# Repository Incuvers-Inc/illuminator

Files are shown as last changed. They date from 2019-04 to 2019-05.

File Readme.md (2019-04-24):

# Illuminator
LED Matrix illuminator for IRIS. Because, as any photographer will say, "good lighting is always needed to take a good picture."

## Hardware
- resistor network (one resistor per LED, 256 in total)
- 32x 74HC595 (for 256 outputs total)
- a dimming transistor for the fluorescence LED (5V PWM)
- a trigger transistor for the fluorescence LED (3.3V logic)
- a logic level shifter (four 3.3V -> 5V)
- capacitors to reduce kicks in current draw

### Power
The main power source will be used for the both illumination modules (matrix+ fluorescence LED). This can potentially blow the fuse is all of the components happen to be active at the same time. Luckily there is no requirement for them to simultaneously be active. The lighting flash is much shorter than the timescales for the environmental controls, so the latter can be disabled for the duration of the lighting flash. This must however be controlled by the software. Failure to account for this may result in a blown fuse.

### LED matrix
The fluorescence LED must first be disabled before the matrix LED is activated.

The LED matrix is driven by `74HC595` shift registers that can holds the state of up to 8 LEDs. The state of all the LED's must be first set before they are globally activated by grounding their shared `output_enable` pin.

#### Dimming
Global dimming is made possible with PWM on the `output_enable` input of the `74HC595`. All only one PWM signal is needed to dim the full matrix.

### Fluorescence LED
All the matrix LEDs must first be disabled before the fluorescence LED is lit.
The on/off state of the fluorescence LED is set from a single transistor.

#### Dimming
Dimming for the fluorescence LED is accomplished using the same PWM signal. In order for the matrix to stay off when the fluorescence LED is enabled, all the individual matrix LEDs must first be disabled.

### RPi interface
The RPi supplies inputs as the common PWM, fluorescence LED trigger, SPI for the matrix (three inputs) and of course a common ground.

Since the matrix is powered at 5V, the logic level (SPI and PWM) has to also be  shifted to 5V.

Since the fluorescence LED is trigger from a transistor, the logic level can stay at 3.3V.

## Software

### Illumination flash

The software must make sure that all the matrix LEDs are set to an `off` state after a pattern is finished flashing.
Iy may be good measure to be redundant and also do this before turning on the fluorescence LED.
The same goes for turning off the fluorescence LED before turning on the matrix.

### Power management

Since the LED's are powered from the main power source,
it is important to limit the total current draw from activated sub-components.
It is the software's responsibility to temporary disable components (heating/fans/valves) that could draw current for the duration of the illumination flash. Since this is rather short, it should cause any environmental noticeable disruptions.

NOTE: the activated camera sensor (and post processing) will also cause a short-lived increase in power demand, consider reactivating the environmental subcomponents only after the image is processed.

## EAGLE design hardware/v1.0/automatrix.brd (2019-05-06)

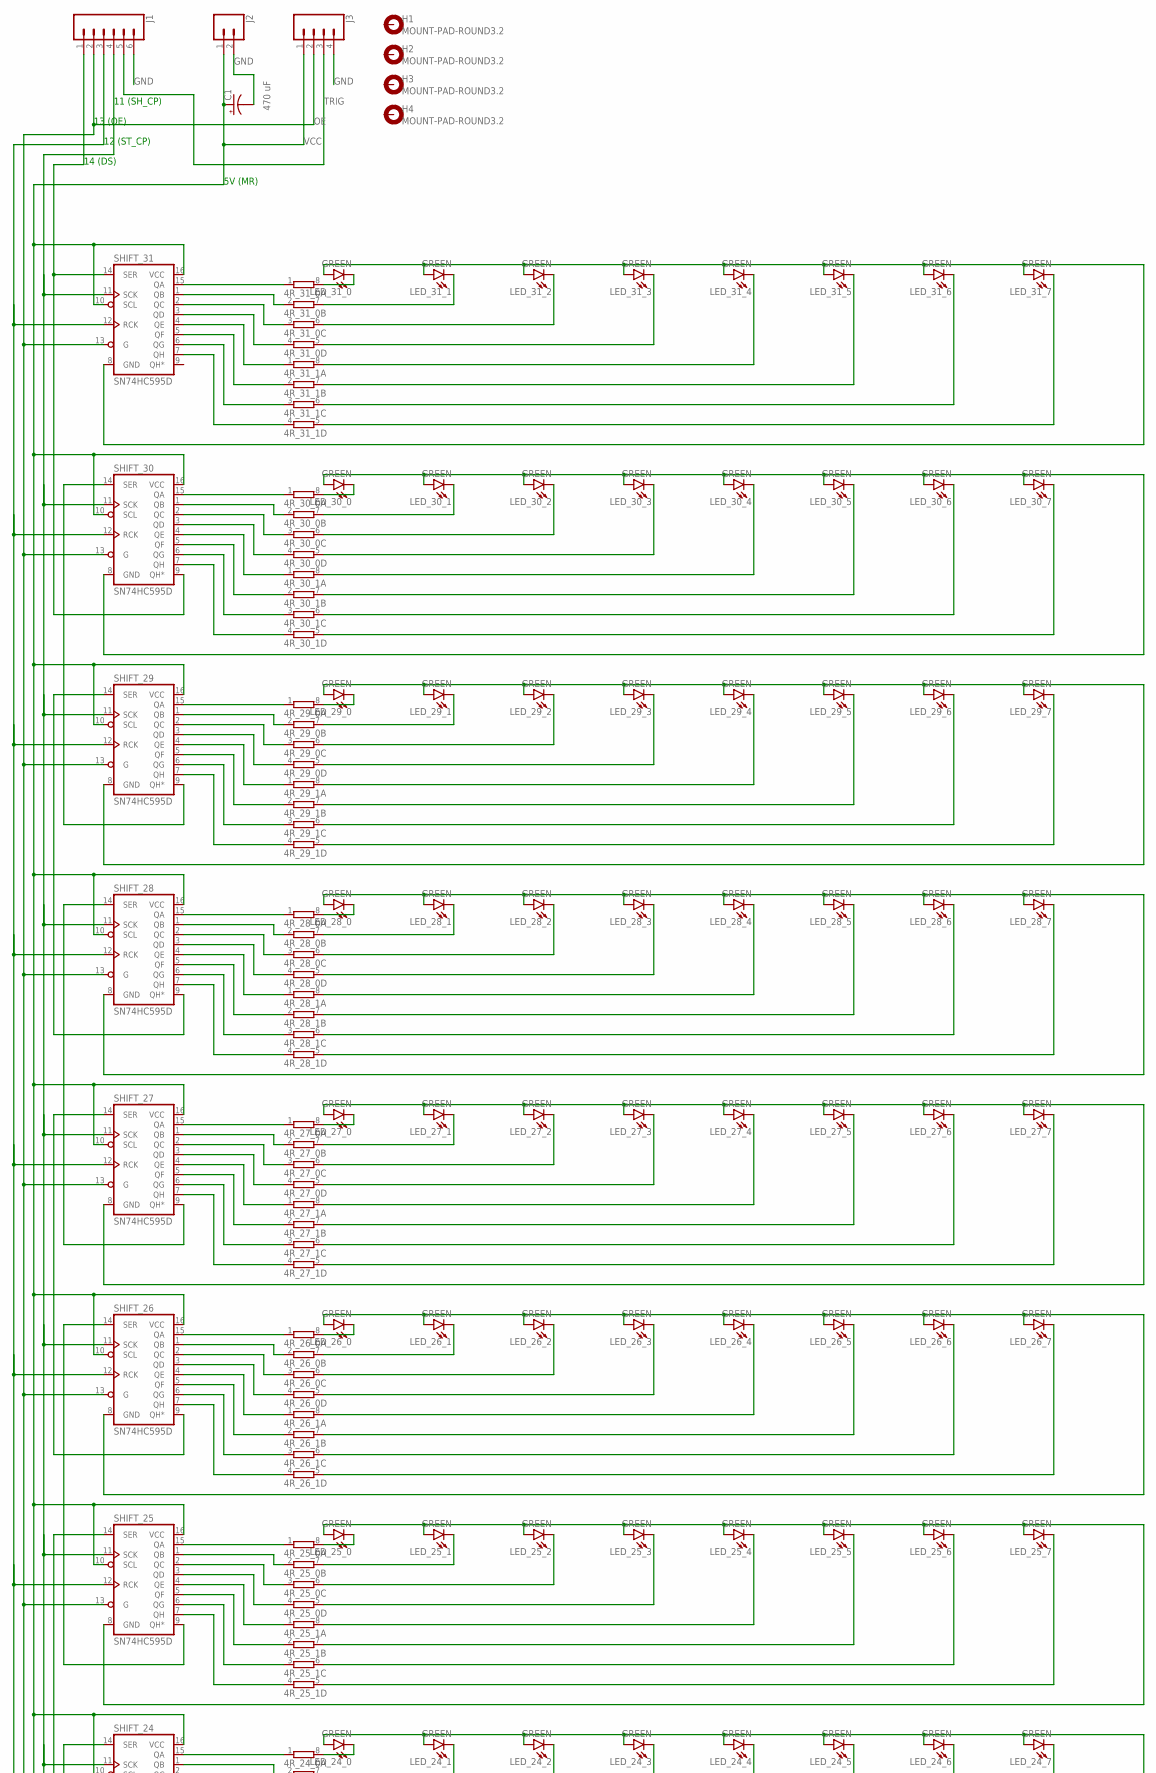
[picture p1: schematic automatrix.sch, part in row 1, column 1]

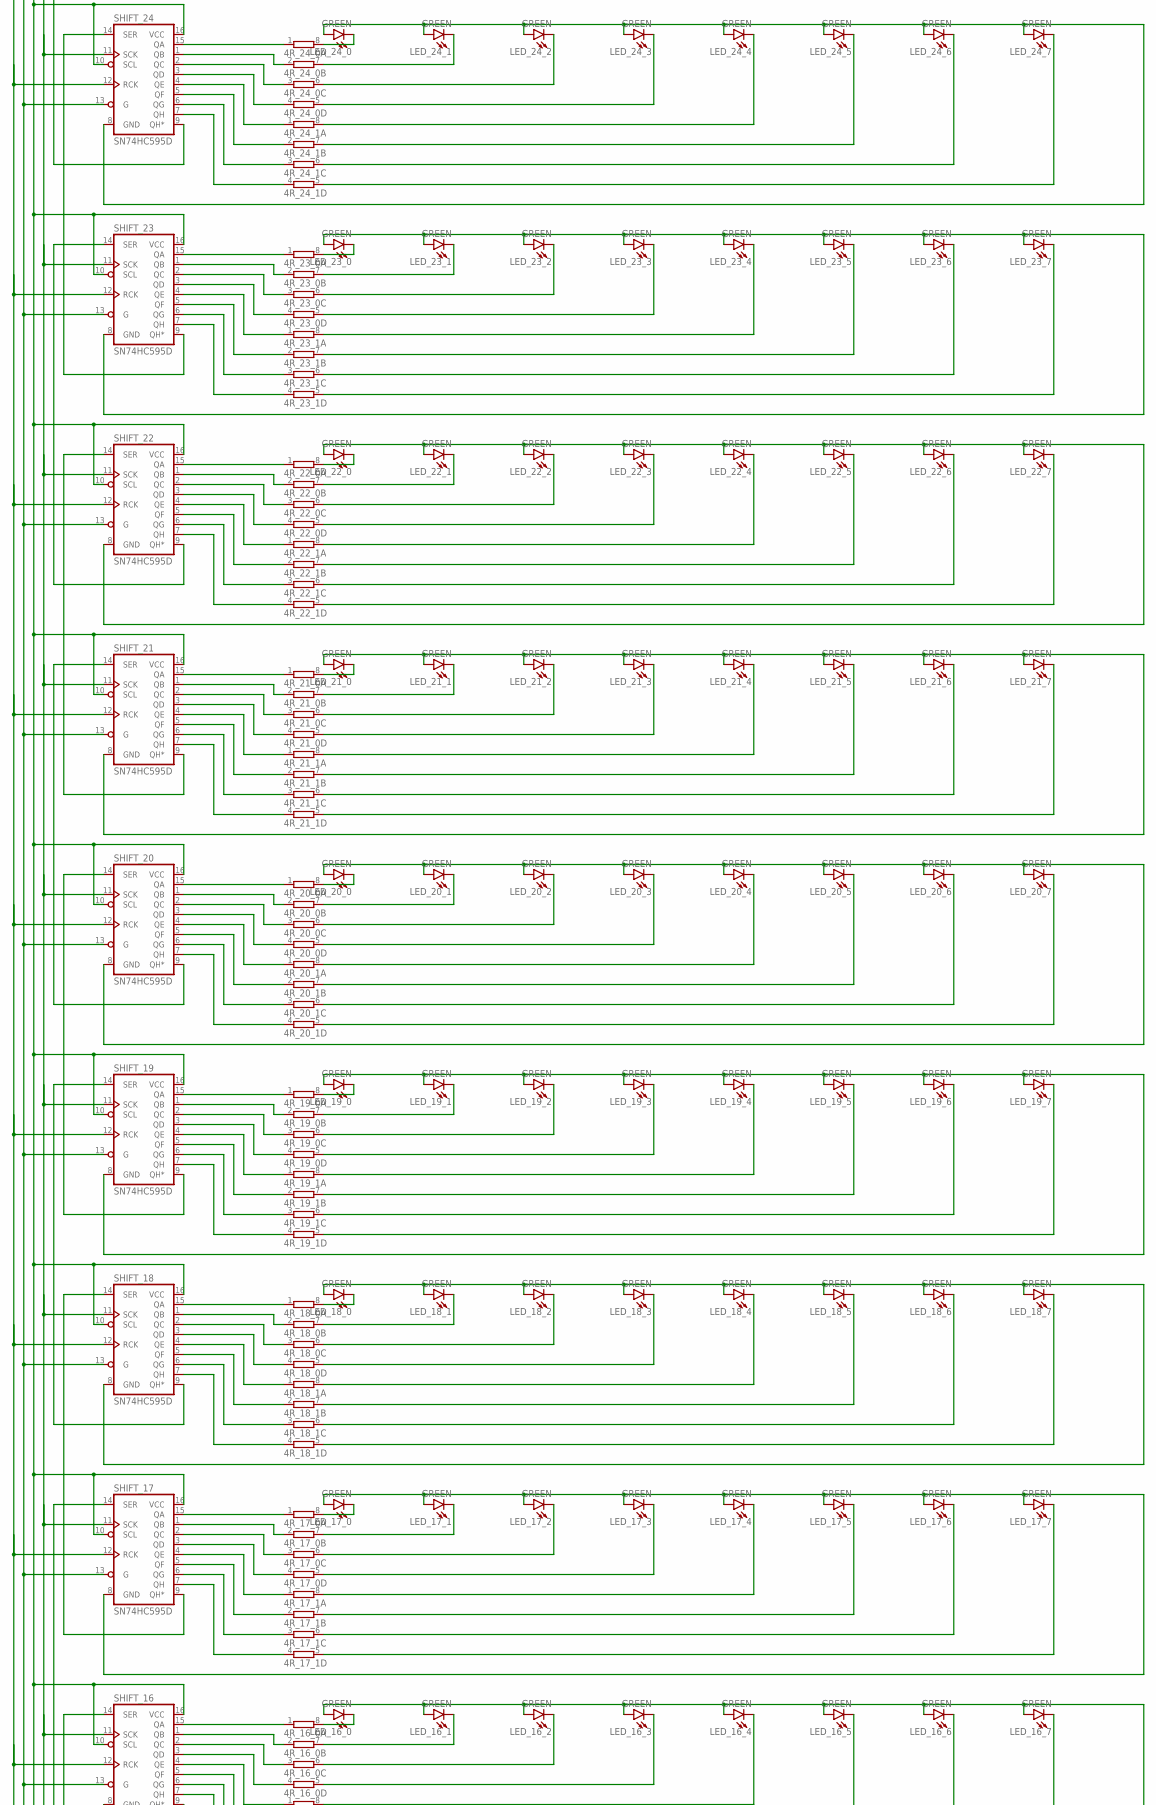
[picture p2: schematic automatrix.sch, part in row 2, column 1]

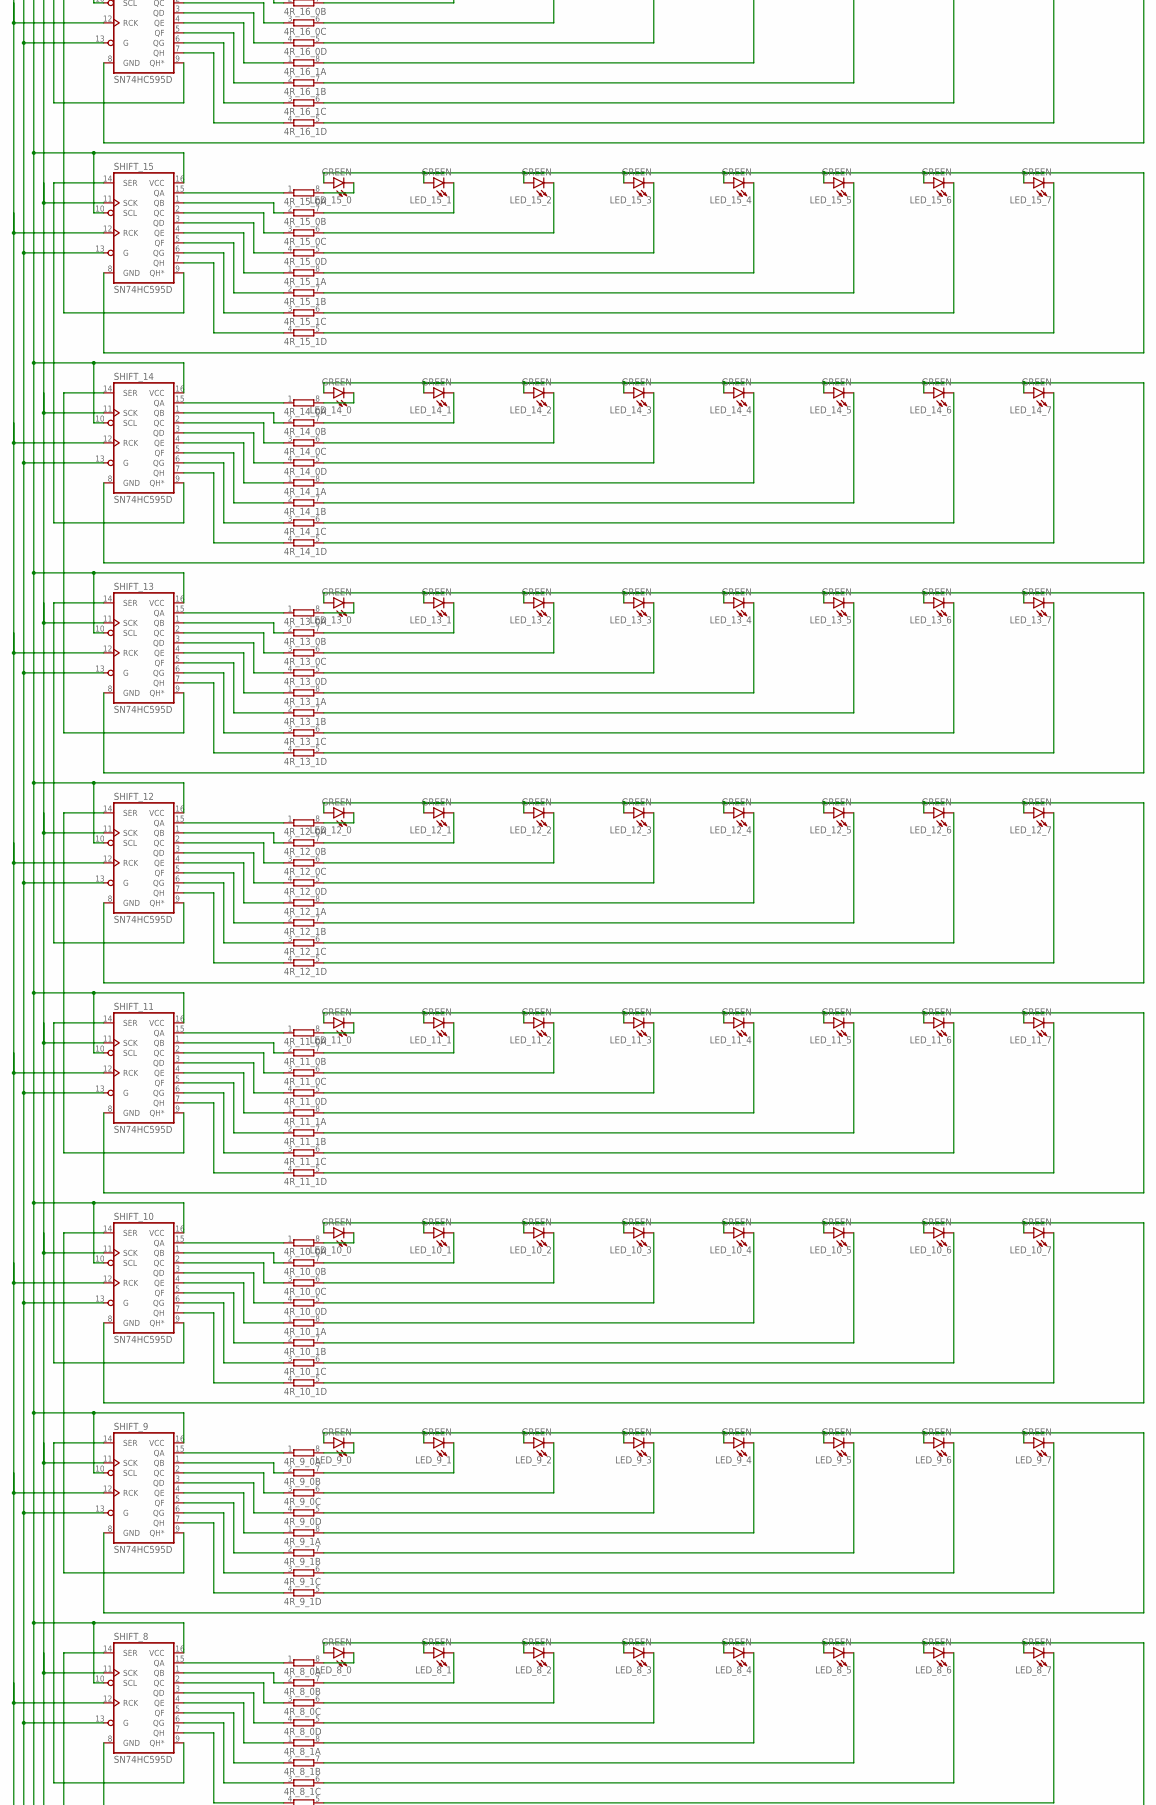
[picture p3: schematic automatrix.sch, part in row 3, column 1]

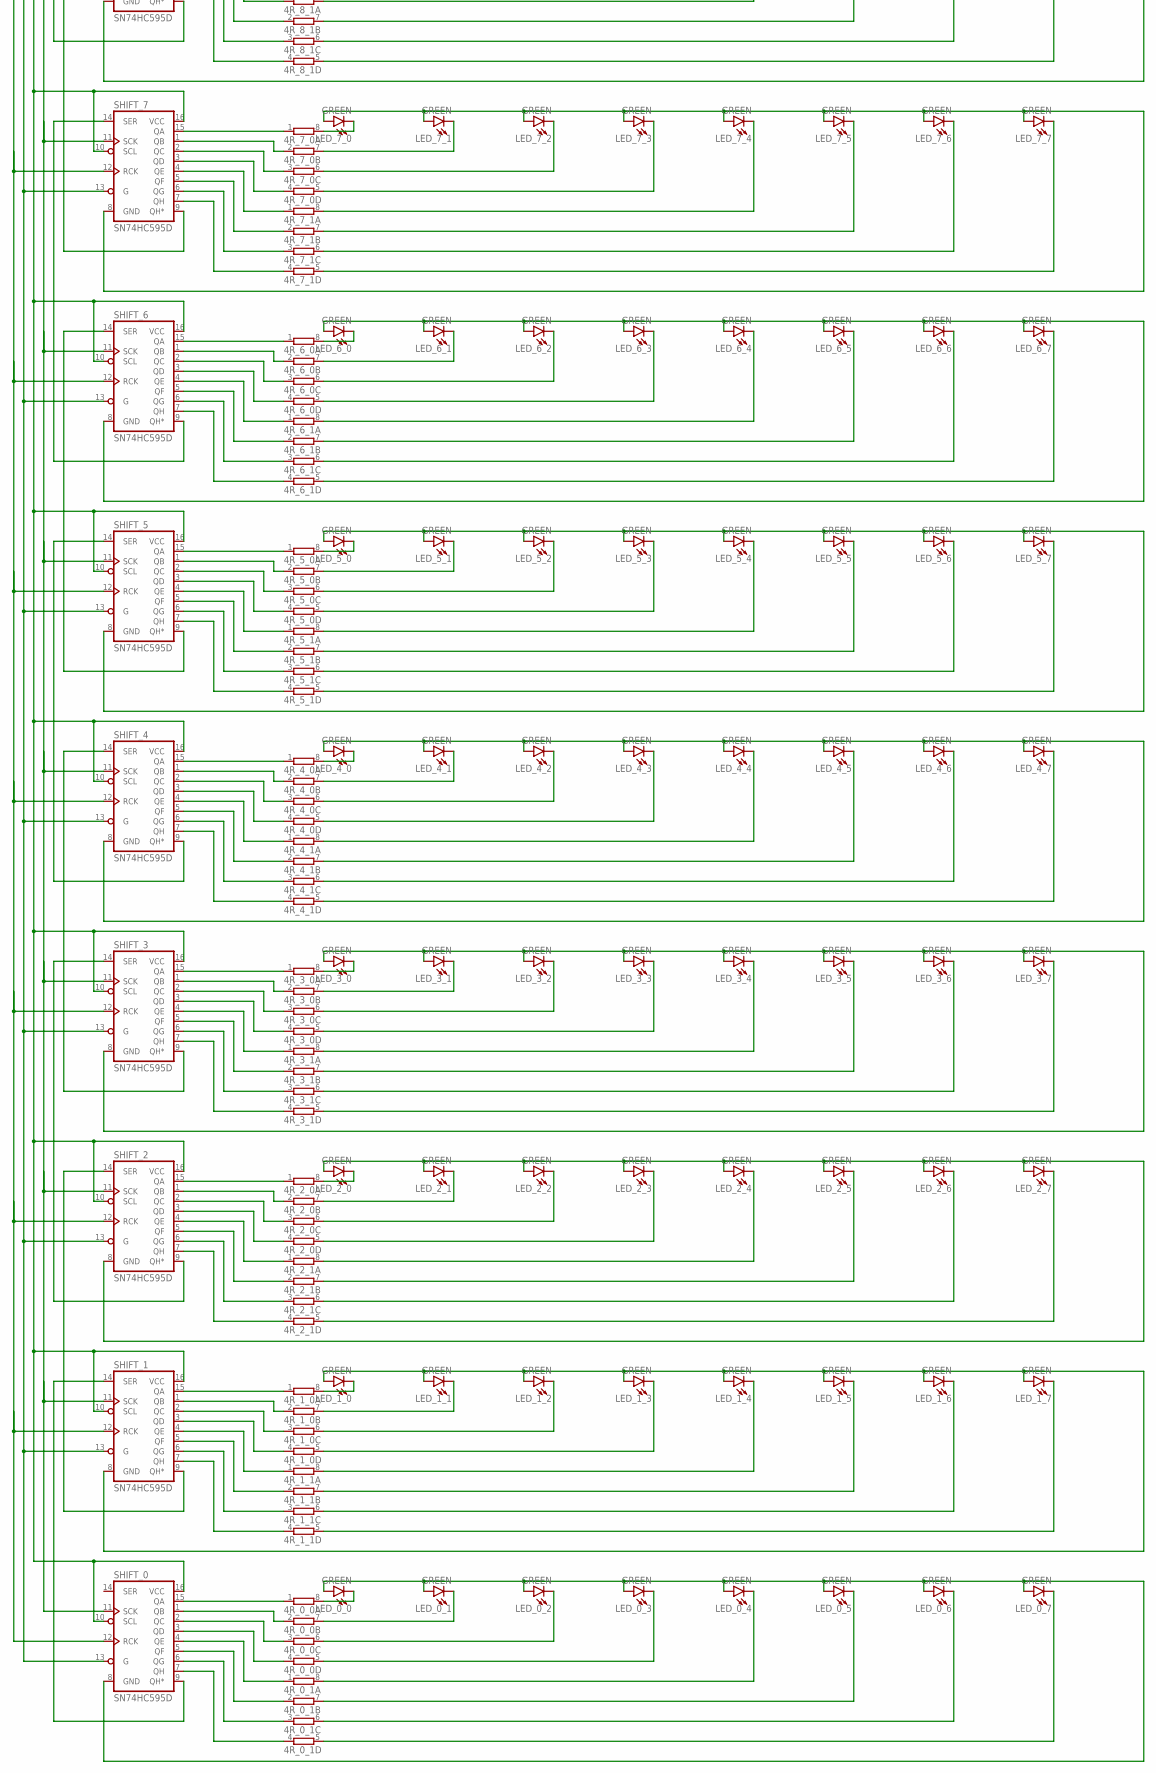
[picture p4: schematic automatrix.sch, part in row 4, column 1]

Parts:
4R_0_0, 4R_0_1, 4R_1_0, 4R_1_1, 4R_2_0, 4R_2_1, 4R_3_0, 4R_3_1, 4R_4_0, 4R_4_1, 4R_5_0, 4R_5_1, 4R_6_0, 4R_6_1, 4R_7_0, 4R_7_1, 4R_8_0, 4R_8_1, 4R_9_0, 4R_9_1, 4R_10_0, 4R_10_1, 4R_11_0, 4R_11_1, 4R_12_0, 4R_12_1, 4R_13_0, 4R_13_1, 4R_14_0, 4R_14_1, 4R_15_0, 4R_15_1, 4R_16_0, 4R_16_1, 4R_17_0, 4R_17_1, 4R_18_0, 4R_18_1, 4R_19_0, 4R_19_1, 4R_20_0, 4R_20_1, 4R_21_0, 4R_21_1, 4R_22_0, 4R_22_1, 4R_23_0, 4R_23_1, 4R_24_0, 4R_24_1, 4R_25_0, 4R_25_1, 4R_26_0, 4R_26_1, 4R_27_0, 4R_27_1, 4R_28_0, 4R_28_1, 4R_29_0, 4R_29_1, 4R_30_0, 4R_30_1, 4R_31_0, 4R_31_1: 4R-N0603-ARC; 0603-ARC
C1: 470 uF; CPOL-RADIAL-5MM-10MM
H1, H2, H3, H4: MOUNT-PAD-ROUND3.2; 3,2-PAD
J1: CONN_06NO_SILK_FEMALE_PTH; 1X06_NO_SILK
J2: CONN_021X02_NO_SILK; 1X02_NO_SILK
J3: CONN_041X04_NO_SILK; 1X04_NO_SILK
LED_0_0, LED_0_1, LED_0_2, LED_0_3, LED_0_4, LED_0_5, LED_0_6, LED_0_7, LED_1_0, LED_1_1, LED_1_2, LED_1_3, LED_1_4, LED_1_5, LED_1_6, LED_1_7, LED_2_0, LED_2_1, LED_2_2, LED_2_3, LED_2_4, LED_2_5, LED_2_6, LED_2_7, LED_3_0, LED_3_1, LED_3_2, LED_3_3, LED_3_4, LED_3_5, LED_3_6, LED_3_7, LED_4_0, LED_4_1, LED_4_2, LED_4_3, LED_4_4, LED_4_5, LED_4_6, LED_4_7, LED_5_0, LED_5_1, LED_5_2, LED_5_3, LED_5_4, LED_5_5, LED_5_6, LED_5_7, LED_6_0, LED_6_1, LED_6_2, LED_6_3, LED_6_4, LED_6_5, LED_6_6, LED_6_7, LED_7_0, LED_7_1, LED_7_2, LED_7_3, LED_7_4, LED_7_5, LED_7_6, LED_7_7, LED_8_0, LED_8_1, LED_8_2, LED_8_3, LED_8_4, LED_8_5, LED_8_6, LED_8_7, LED_9_0, LED_9_1, LED_9_2, LED_9_3, LED_9_4, LED_9_5, LED_9_6, LED_9_7, LED_10_0, LED_10_1, LED_10_2, LED_10_3, LED_10_4, LED_10_5, LED_10_6, LED_10_7, LED_11_0, LED_11_1, LED_11_2, LED_11_3, LED_11_4, LED_11_5, LED_11_6, LED_11_7, LED_12_0, LED_12_1, LED_12_2, LED_12_3, LED_12_4, LED_12_5, LED_12_6, LED_12_7, LED_13_0, LED_13_1, LED_13_2, LED_13_3, LED_13_4, LED_13_5, LED_13_6, LED_13_7, LED_14_0, LED_14_1, LED_14_2, LED_14_3, LED_14_4, LED_14_5, LED_14_6, LED_14_7, LED_15_0, LED_15_1, LED_15_2, LED_15_3, LED_15_4, LED_15_5, LED_15_6, LED_15_7, LED_16_0, LED_16_1, LED_16_2, LED_16_3, LED_16_4, LED_16_5, LED_16_6, LED_16_7, LED_17_0, LED_17_1, LED_17_2, LED_17_3, LED_17_4, LED_17_5, LED_17_6, LED_17_7, LED_18_0, LED_18_1, LED_18_2, LED_18_3, LED_18_4, LED_18_5, LED_18_6, LED_18_7, LED_19_0, LED_19_1, LED_19_2, LED_19_3, LED_19_4, LED_19_5, LED_19_6, LED_19_7, LED_20_0, LED_20_1, LED_20_2, LED_20_3, LED_20_4, LED_20_5, LED_20_6, LED_20_7, LED_21_0, LED_21_1, LED_21_2, LED_21_3, LED_21_4, LED_21_5, LED_21_6, LED_21_7, LED_22_0, LED_22_1, LED_22_2, LED_22_3, LED_22_4, LED_22_5, LED_22_6, LED_22_7, LED_23_0, LED_23_1, LED_23_2, LED_23_3, LED_23_4, LED_23_5, LED_23_6, LED_23_7, LED_24_0, LED_24_1, LED_24_2, LED_24_3, LED_24_4, LED_24_5, LED_24_6, LED_24_7, LED_25_0, LED_25_1, LED_25_2, LED_25_3, LED_25_4, LED_25_5, LED_25_6, LED_25_7, LED_26_0, LED_26_1, LED_26_2, LED_26_3, LED_26_4, LED_26_5, LED_26_6, LED_26_7, LED_27_0, LED_27_1, LED_27_2, LED_27_3, LED_27_4, LED_27_5, LED_27_6, LED_27_7, LED_28_0, LED_28_1, LED_28_2, LED_28_3, LED_28_4, LED_28_5, LED_28_6, LED_28_7, LED_29_0, LED_29_1, LED_29_2, LED_29_3, LED_29_4, LED_29_5, LED_29_6, LED_29_7, LED_30_0, LED_30_1, LED_30_2, LED_30_3, LED_30_4, LED_30_5, LED_30_6, LED_30_7, LED_31_0, LED_31_1, LED_31_2, LED_31_3, LED_31_4, LED_31_5, LED_31_6, LED_31_7: GREEN; LED-0603
SHIFT_0, SHIFT_1, SHIFT_2, SHIFT_3, SHIFT_4, SHIFT_5, SHIFT_6, SHIFT_7, SHIFT_8, SHIFT_9, SHIFT_10, SHIFT_11, SHIFT_12, SHIFT_13, SHIFT_14, SHIFT_15, SHIFT_16, SHIFT_17, SHIFT_18, SHIFT_19, SHIFT_20, SHIFT_21, SHIFT_22, SHIFT_23, SHIFT_24, SHIFT_25, SHIFT_26, SHIFT_27, SHIFT_28, SHIFT_29, SHIFT_30, SHIFT_31: SN74HC595D; SO16

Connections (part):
CLK: J1.4, SHIFT_0.11 (SCK), SHIFT_1.11 (SCK), SHIFT_2.11 (SCK), SHIFT_3.11 (SCK), SHIFT_4.11 (SCK), SHIFT_5.11 (SCK), SHIFT_6.11 (SCK), SHIFT_7.11 (SCK), SHIFT_8.11 (SCK), SHIFT_9.11 (SCK), SHIFT_10.11 (SCK), SHIFT_11.11 (SCK), SHIFT_12.11 (SCK), SHIFT_13.11 (SCK), SHIFT_14.11 (SCK), SHIFT_15.11 (SCK), SHIFT_16.11 (SCK), SHIFT_17.11 (SCK), SHIFT_18.11 (SCK), SHIFT_19.11 (SCK), SHIFT_20.11 (SCK), SHIFT_21.11 (SCK), SHIFT_22.11 (SCK), SHIFT_23.11 (SCK), SHIFT_24.11 (SCK), SHIFT_25.11 (SCK), SHIFT_26.11 (SCK), SHIFT_27.11 (SCK), SHIFT_28.11 (SCK), SHIFT_29.11 (SCK), SHIFT_30.11 (SCK), SHIFT_31.11 (SCK)
GND: C1.-, J1.6, J2.2, J3.4, LED_0_0.A, LED_0_1.A, LED_0_2.A, LED_0_3.A, LED_0_4.A, LED_0_5.A, LED_0_6.A, LED_0_7.A, LED_1_0.A, LED_1_1.A, LED_1_2.A, LED_1_3.A, LED_1_4.A, LED_1_5.A, LED_1_6.A, LED_1_7.A, LED_2_0.A, LED_2_1.A, LED_2_2.A, LED_2_3.A, LED_2_4.A, LED_2_5.A, LED_2_6.A, LED_2_7.A, LED_3_0.A, LED_3_1.A, LED_3_2.A, LED_3_3.A, LED_3_4.A, LED_3_5.A, LED_3_6.A, LED_3_7.A, LED_4_0.A, LED_4_1.A, LED_4_2.A, LED_4_3.A, LED_4_4.A, LED_4_5.A, LED_4_6.A, LED_4_7.A, LED_5_0.A, LED_5_1.A, LED_5_2.A, LED_5_3.A, LED_5_4.A, LED_5_5.A, LED_5_6.A, LED_5_7.A, LED_6_0.A, LED_6_1.A, LED_6_2.A, LED_6_3.A, LED_6_4.A, LED_6_5.A, LED_6_6.A, LED_6_7.A, LED_7_0.A, LED_7_1.A, LED_7_2.A, LED_7_3.A, LED_7_4.A, LED_7_5.A, LED_7_6.A, LED_7_7.A, LED_8_0.A, LED_8_1.A, LED_8_2.A, LED_8_3.A, LED_8_4.A, LED_8_5.A, LED_8_6.A, LED_8_7.A, LED_9_0.A, LED_9_1.A, LED_9_2.A, LED_9_3.A, LED_9_4.A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
OE: J1.2, J3.2, SHIFT_0.13 (G), SHIFT_1.13 (G), SHIFT_2.13 (G), SHIFT_3.13 (G), SHIFT_4.13 (G), SHIFT_5.13 (G), SHIFT_6.13 (G), SHIFT_7.13 (G), SHIFT_8.13 (G), SHIFT_9.13 (G), SHIFT_10.13 (G), SHIFT_11.13 (G), SHIFT_12.13 (G), SHIFT_13.13 (G), SHIFT_14.13 (G), SHIFT_15.13 (G), SHIFT_16.13 (G), SHIFT_17.13 (G), SHIFT_18.13 (G), SHIFT_19.13 (G), SHIFT_20.13 (G), SHIFT_21.13 (G), SHIFT_22.13 (G), SHIFT_23.13 (G), SHIFT_24.13 (G), SHIFT_25.13 (G), SHIFT_26.13 (G), SHIFT_27.13 (G), SHIFT_28.13 (G), SHIFT_29.13 (G), SHIFT_30.13 (G), SHIFT_31.13 (G)
Q0_0: 4R_0_0.1, 4R_0_0.8 (2), LED_0_0.C, SHIFT_0.15 (QA)
Q0_1: 4R_0_0.2 (1), 4R_0_0.7 (2), LED_0_1.C, SHIFT_0.1 (QB)
Q0_2: 4R_0_0.3 (1), 4R_0_0.6 (2), LED_0_2.C, SHIFT_0.2 (QC)
Q0_3: 4R_0_0.4 (1), 4R_0_0.5 (2), LED_0_3.C, SHIFT_0.3 (QD)
Q0_4: 4R_0_1.1, 4R_0_1.8 (2), LED_0_4.C, SHIFT_0.4 (QE)
Q0_5: 4R_0_1.2 (1), 4R_0_1.7 (2), LED_0_5.C, SHIFT_0.5 (QF)
Q0_6: 4R_0_1.3 (1), 4R_0_1.6 (2), LED_0_6.C, SHIFT_0.6 (QG)
Q0_7: 4R_0_1.4 (1), 4R_0_1.5 (2), LED_0_7.C, SHIFT_0.7 (QH)
Q1_0: 4R_1_0.1, 4R_1_0.8 (2), LED_1_0.C, SHIFT_1.15 (QA)
Q1_1: 4R_1_0.2 (1), 4R_1_0.7 (2), LED_1_1.C, SHIFT_1.1 (QB)
Q1_2: 4R_1_0.3 (1), 4R_1_0.6 (2), LED_1_2.C, SHIFT_1.2 (QC)
Q1_3: 4R_1_0.4 (1), 4R_1_0.5 (2), LED_1_3.C, SHIFT_1.3 (QD)
Q1_4: 4R_1_1.1, 4R_1_1.8 (2), LED_1_4.C, SHIFT_1.4 (QE)
Q1_5: 4R_1_1.2 (1), 4R_1_1.7 (2), LED_1_5.C, SHIFT_1.5 (QF)
Q1_6: 4R_1_1.3 (1), 4R_1_1.6 (2), LED_1_6.C, SHIFT_1.6 (QG)
Q1_7: 4R_1_1.4 (1), 4R_1_1.5 (2), LED_1_7.C, SHIFT_1.7 (QH)
Q2_0: 4R_2_0.1, 4R_2_0.8 (2), LED_2_0.C, SHIFT_2.15 (QA)
Q2_1: 4R_2_0.2 (1), 4R_2_0.7 (2), LED_2_1.C, SHIFT_2.1 (QB)
Q2_2: 4R_2_0.3 (1), 4R_2_0.6 (2), LED_2_2.C, SHIFT_2.2 (QC)
Q2_3: 4R_2_0.4 (1), 4R_2_0.5 (2), LED_2_3.C, SHIFT_2.3 (QD)
Q2_4: 4R_2_1.1, 4R_2_1.8 (2), LED_2_4.C, SHIFT_2.4 (QE)
Q2_5: 4R_2_1.2 (1), 4R_2_1.7 (2), LED_2_5.C, SHIFT_2.5 (QF)
Q2_6: 4R_2_1.3 (1), 4R_2_1.6 (2), LED_2_6.C, SHIFT_2.6 (QG)
Q2_7: 4R_2_1.4 (1), 4R_2_1.5 (2), LED_2_7.C, SHIFT_2.7 (QH)
Q3_0: 4R_3_0.1, 4R_3_0.8 (2), LED_3_0.C, SHIFT_3.15 (QA)
Q3_1: 4R_3_0.2 (1), 4R_3_0.7 (2), LED_3_1.C, SHIFT_3.1 (QB)
Q3_2: 4R_3_0.3 (1), 4R_3_0.6 (2), LED_3_2.C, SHIFT_3.2 (QC)
Q3_3: 4R_3_0.4 (1), 4R_3_0.5 (2), LED_3_3.C, SHIFT_3.3 (QD)
Q3_4: 4R_3_1.1, 4R_3_1.8 (2), LED_3_4.C, SHIFT_3.4 (QE)
Q3_5: 4R_3_1.2 (1), 4R_3_1.7 (2), LED_3_5.C, SHIFT_3.5 (QF)
Q3_6: 4R_3_1.3 (1), 4R_3_1.6 (2), LED_3_6.C, SHIFT_3.6 (QG)
Q3_7: 4R_3_1.4 (1), 4R_3_1.5 (2), LED_3_7.C, SHIFT_3.7 (QH)
Q4_0: 4R_4_0.1, 4R_4_0.8 (2), LED_4_0.C, SHIFT_4.15 (QA)
Q4_1: 4R_4_0.2 (1), 4R_4_0.7 (2), LED_4_1.C, SHIFT_4.1 (QB)
Q4_2: 4R_4_0.3 (1), 4R_4_0.6 (2), LED_4_2.C, SHIFT_4.2 (QC)
Q4_3: 4R_4_0.4 (1), 4R_4_0.5 (2), LED_4_3.C, SHIFT_4.3 (QD)
Q4_4: 4R_4_1.1, 4R_4_1.8 (2), LED_4_4.C, SHIFT_4.4 (QE)
Q4_5: 4R_4_1.2 (1), 4R_4_1.7 (2), LED_4_5.C, SHIFT_4.5 (QF)
Q4_6: 4R_4_1.3 (1), 4R_4_1.6 (2), LED_4_6.C, SHIFT_4.6 (QG)
Q4_7: 4R_4_1.4 (1), 4R_4_1.5 (2), LED_4_7.C, SHIFT_4.7 (QH)
Q5_0: 4R_5_0.1, 4R_5_0.8 (2), LED_5_0.C, SHIFT_5.15 (QA)
Q5_1: 4R_5_0.2 (1), 4R_5_0.7 (2), LED_5_1.C, SHIFT_5.1 (QB)
Q5_2: 4R_5_0.3 (1), 4R_5_0.6 (2), LED_5_2.C, SHIFT_5.2 (QC)
Q5_3: 4R_5_0.4 (1), 4R_5_0.5 (2), LED_5_3.C, SHIFT_5.3 (QD)
Q5_4: 4R_5_1.1, 4R_5_1.8 (2), LED_5_4.C, SHIFT_5.4 (QE)
Q5_5: 4R_5_1.2 (1), 4R_5_1.7 (2), LED_5_5.C, SHIFT_5.5 (QF)
Q5_6: 4R_5_1.3 (1), 4R_5_1.6 (2), LED_5_6.C, SHIFT_5.6 (QG)
Q5_7: 4R_5_1.4 (1), 4R_5_1.5 (2), LED_5_7.C, SHIFT_5.7 (QH)
Q6_0: 4R_6_0.1, 4R_6_0.8 (2), LED_6_0.C, SHIFT_6.15 (QA)
Q6_1: 4R_6_0.2 (1), 4R_6_0.7 (2), LED_6_1.C, SHIFT_6.1 (QB)
Q6_2: 4R_6_0.3 (1), 4R_6_0.6 (2), LED_6_2.C, SHIFT_6.2 (QC)
Q6_3: 4R_6_0.4 (1), 4R_6_0.5 (2), LED_6_3.C, SHIFT_6.3 (QD)
Q6_4: 4R_6_1.1, 4R_6_1.8 (2), LED_6_4.C, SHIFT_6.4 (QE)
Q6_5: 4R_6_1.2 (1), 4R_6_1.7 (2), LED_6_5.C, SHIFT_6.5 (QF)
Q6_6: 4R_6_1.3 (1), 4R_6_1.6 (2), LED_6_6.C, SHIFT_6.6 (QG)
Q6_7: 4R_6_1.4 (1), 4R_6_1.5 (2), LED_6_7.C, SHIFT_6.7 (QH)
Q7_0: 4R_7_0.1, 4R_7_0.8 (2), LED_7_0.C, SHIFT_7.15 (QA)
Q7_1: 4R_7_0.2 (1), 4R_7_0.7 (2), LED_7_1.C, SHIFT_7.1 (QB)
Q7_2: 4R_7_0.3 (1), 4R_7_0.6 (2), LED_7_2.C, SHIFT_7.2 (QC)
Q7_3: 4R_7_0.4 (1), 4R_7_0.5 (2), LED_7_3.C, SHIFT_7.3 (QD)
Q7_4: 4R_7_1.1, 4R_7_1.8 (2), LED_7_4.C, SHIFT_7.4 (QE)
Q7_5: 4R_7_1.2 (1), 4R_7_1.7 (2), LED_7_5.C, SHIFT_7.5 (QF)
Q7_6: 4R_7_1.3 (1), 4R_7_1.6 (2), LED_7_6.C, SHIFT_7.6 (QG)
Q7_7: 4R_7_1.4 (1), 4R_7_1.5 (2), LED_7_7.C, SHIFT_7.7 (QH)
Q8_0: 4R_8_0.1, 4R_8_0.8 (2), LED_8_0.C, SHIFT_8.15 (QA)
Q8_1: 4R_8_0.2 (1), 4R_8_0.7 (2), LED_8_1.C, SHIFT_8.1 (QB)
Q8_2: 4R_8_0.3 (1), 4R_8_0.6 (2), LED_8_2.C, SHIFT_8.2 (QC)
Q8_3: 4R_8_0.4 (1), 4R_8_0.5 (2), LED_8_3.C, SHIFT_8.3 (QD)
Q8_4: 4R_8_1.1, 4R_8_1.8 (2), LED_8_4.C, SHIFT_8.4 (QE)
Q8_5: 4R_8_1.2 (1), 4R_8_1.7 (2), LED_8_5.C, SHIFT_8.5 (QF)
Q8_6: 4R_8_1.3 (1), 4R_8_1.6 (2), LED_8_6.C, SHIFT_8.6 (QG)
Q8_7: 4R_8_1.4 (1), 4R_8_1.5 (2), LED_8_7.C, SHIFT_8.7 (QH)
Q9_0: 4R_9_0.1, 4R_9_0.8 (2), LED_9_0.C, SHIFT_9.15 (QA)
Q9_1: 4R_9_0.2 (1), 4R_9_0.7 (2), LED_9_1.C, SHIFT_9.1 (QB)
Q9_2: 4R_9_0.3 (1), 4R_9_0.6 (2), LED_9_2.C, SHIFT_9.2 (QC)
Q9_3: 4R_9_0.4 (1), 4R_9_0.5 (2), LED_9_3.C, SHIFT_9.3 (QD)
Q9_4: 4R_9_1.1, 4R_9_1.8 (2), LED_9_4.C, SHIFT_9.4 (QE)
Q9_5: 4R_9_1.2 (1), 4R_9_1.7 (2), LED_9_5.C, SHIFT_9.5 (QF)
Q9_6: 4R_9_1.3 (1), 4R_9_1.6 (2), LED_9_6.C, SHIFT_9.6 (QG)
Q9_7: 4R_9_1.4 (1), 4R_9_1.5 (2), LED_9_7.C, SHIFT_9.7 (QH)
Q10_0: 4R_10_0.1, 4R_10_0.8 (2), LED_10_0.C, SHIFT_10.15 (QA)
Q10_1: 4R_10_0.2 (1), 4R_10_0.7 (2), LED_10_1.C, SHIFT_10.1 (QB)
Q10_2: 4R_10_0.3 (1), 4R_10_0.6 (2), LED_10_2.C, SHIFT_10.2 (QC)
Q10_3: 4R_10_0.4 (1), 4R_10_0.5 (2), LED_10_3.C, SHIFT_10.3 (QD)
Q10_4: 4R_10_1.1, 4R_10_1.8 (2), LED_10_4.C, SHIFT_10.4 (QE)
Q10_5: 4R_10_1.2 (1), 4R_10_1.7 (2), LED_10_5.C, SHIFT_10.5 (QF)
Q10_6: 4R_10_1.3 (1), 4R_10_1.6 (2), LED_10_6.C, SHIFT_10.6 (QG)
Q10_7: 4R_10_1.4 (1), 4R_10_1.5 (2), LED_10_7.C, SHIFT_10.7 (QH)
Q11_0: 4R_11_0.1, 4R_11_0.8 (2), LED_11_0.C, SHIFT_11.15 (QA)
Q11_1: 4R_11_0.2 (1), 4R_11_0.7 (2), LED_11_1.C, SHIFT_11.1 (QB)
Q11_2: 4R_11_0.3 (1), 4R_11_0.6 (2), LED_11_2.C, SHIFT_11.2 (QC)
Q11_3: 4R_11_0.4 (1), 4R_11_0.5 (2), LED_11_3.C, SHIFT_11.3 (QD)
Q11_4: 4R_11_1.1, 4R_11_1.8 (2), LED_11_4.C, SHIFT_11.4 (QE)
Q11_5: 4R_11_1.2 (1), 4R_11_1.7 (2), LED_11_5.C, SHIFT_11.5 (QF)
Q11_6: 4R_11_1.3 (1), 4R_11_1.6 (2), LED_11_6.C, SHIFT_11.6 (QG)
Q11_7: 4R_11_1.4 (1), 4R_11_1.5 (2), LED_11_7.C, SHIFT_11.7 (QH)
Q12_0: 4R_12_0.1, 4R_12_0.8 (2), LED_12_0.C, SHIFT_12.15 (QA)
Q12_1: 4R_12_0.2 (1), 4R_12_0.7 (2), LED_12_1.C, SHIFT_12.1 (QB)
Q12_2: 4R_12_0.3 (1), 4R_12_0.6 (2), LED_12_2.C, SHIFT_12.2 (QC)
Q12_3: 4R_12_0.4 (1), 4R_12_0.5 (2), LED_12_3.C, SHIFT_12.3 (QD)
Q12_4: 4R_12_1.1, 4R_12_1.8 (2), LED_12_4.C, SHIFT_12.4 (QE)
Q12_5: 4R_12_1.2 (1), 4R_12_1.7 (2), LED_12_5.C, SHIFT_12.5 (QF)
Q12_6: 4R_12_1.3 (1), 4R_12_1.6 (2), LED_12_6.C, SHIFT_12.6 (QG)
Q12_7: 4R_12_1.4 (1), 4R_12_1.5 (2), LED_12_7.C, SHIFT_12.7 (QH)
Q13_0: 4R_13_0.1, 4R_13_0.8 (2), LED_13_0.C, SHIFT_13.15 (QA)
Q13_1: 4R_13_0.2 (1), 4R_13_0.7 (2), LED_13_1.C, SHIFT_13.1 (QB)
Q13_2: 4R_13_0.3 (1), 4R_13_0.6 (2), LED_13_2.C, SHIFT_13.2 (QC)
Q13_3: 4R_13_0.4 (1), 4R_13_0.5 (2), LED_13_3.C, SHIFT_13.3 (QD)
Q13_4: 4R_13_1.1, 4R_13_1.8 (2), LED_13_4.C, SHIFT_13.4 (QE)
Q13_5: 4R_13_1.2 (1), 4R_13_1.7 (2), LED_13_5.C, SHIFT_13.5 (QF)
Q13_6: 4R_13_1.3 (1), 4R_13_1.6 (2), LED_13_6.C, SHIFT_13.6 (QG)
Q13_7: 4R_13_1.4 (1), 4R_13_1.5 (2), LED_13_7.C, SHIFT_13.7 (QH)
Q14_0: 4R_14_0.1, 4R_14_0.8 (2), LED_14_0.C, SHIFT_14.15 (QA)
Q14_1: 4R_14_0.2 (1), 4R_14_0.7 (2), LED_14_1.C, SHIFT_14.1 (QB)
Q14_2: 4R_14_0.3 (1), 4R_14_0.6 (2), LED_14_2.C, SHIFT_14.2 (QC)
Q14_3: 4R_14_0.4 (1), 4R_14_0.5 (2), LED_14_3.C, SHIFT_14.3 (QD)
Q14_4: 4R_14_1.1, 4R_14_1.8 (2), LED_14_4.C, SHIFT_14.4 (QE)
Q14_5: 4R_14_1.2 (1), 4R_14_1.7 (2), LED_14_5.C, SHIFT_14.5 (QF)
Q14_6: 4R_14_1.3 (1), 4R_14_1.6 (2), LED_14_6.C, SHIFT_14.6 (QG)
Q14_7: 4R_14_1.4 (1), 4R_14_1.5 (2), LED_14_7.C, SHIFT_14.7 (QH)
Q15_0: 4R_15_0.1, 4R_15_0.8 (2), LED_15_0.C, SHIFT_15.15 (QA)
Q15_1: 4R_15_0.2 (1), 4R_15_0.7 (2), LED_15_1.C, SHIFT_15.1 (QB)
Q15_2: 4R_15_0.3 (1), 4R_15_0.6 (2), LED_15_2.C, SHIFT_15.2 (QC)
Q15_3: 4R_15_0.4 (1), 4R_15_0.5 (2), LED_15_3.C, SHIFT_15.3 (QD)
Q15_4: 4R_15_1.1, 4R_15_1.8 (2), LED_15_4.C, SHIFT_15.4 (QE)
Q15_5: 4R_15_1.2 (1), 4R_15_1.7 (2), LED_15_5.C, SHIFT_15.5 (QF)
Q15_6: 4R_15_1.3 (1), 4R_15_1.6 (2), LED_15_6.C, SHIFT_15.6 (QG)
Q15_7: 4R_15_1.4 (1), 4R_15_1.5 (2), LED_15_7.C, SHIFT_15.7 (QH)
Q16_0: 4R_16_0.1, 4R_16_0.8 (2), LED_16_0.C, SHIFT_16.15 (QA)
Q16_1: 4R_16_0.2 (1), 4R_16_0.7 (2), LED_16_1.C, SHIFT_16.1 (QB)
Q16_2: 4R_16_0.3 (1), 4R_16_0.6 (2), LED_16_2.C, SHIFT_16.2 (QC)
Q16_3: 4R_16_0.4 (1), 4R_16_0.5 (2), LED_16_3.C, SHIFT_16.3 (QD)
Q16_4: 4R_16_1.1, 4R_16_1.8 (2), LED_16_4.C, SHIFT_16.4 (QE)
Q16_5: 4R_16_1.2 (1), 4R_16_1.7 (2), LED_16_5.C, SHIFT_16.5 (QF)
Q16_6: 4R_16_1.3 (1), 4R_16_1.6 (2), LED_16_6.C, SHIFT_16.6 (QG)
Q16_7: 4R_16_1.4 (1), 4R_16_1.5 (2), LED_16_7.C, SHIFT_16.7 (QH)
Q17_0: 4R_17_0.1, 4R_17_0.8 (2), LED_17_0.C, SHIFT_17.15 (QA)
Q17_1: 4R_17_0.2 (1), 4R_17_0.7 (2), LED_17_1.C, SHIFT_17.1 (QB)
Q17_2: 4R_17_0.3 (1), 4R_17_0.6 (2), LED_17_2.C, SHIFT_17.2 (QC)
Q17_3: 4R_17_0.4 (1), 4R_17_0.5 (2), LED_17_3.C, SHIFT_17.3 (QD)
Q17_4: 4R_17_1.1, 4R_17_1.8 (2), LED_17_4.C, SHIFT_17.4 (QE)
Q17_5: 4R_17_1.2 (1), 4R_17_1.7 (2), LED_17_5.C, SHIFT_17.5 (QF)
Q17_6: 4R_17_1.3 (1), 4R_17_1.6 (2), LED_17_6.C, SHIFT_17.6 (QG)
Q17_7: 4R_17_1.4 (1), 4R_17_1.5 (2), LED_17_7.C, SHIFT_17.7 (QH)
Q18_0: 4R_18_0.1, 4R_18_0.8 (2), LED_18_0.C, SHIFT_18.15 (QA)
Q18_1: 4R_18_0.2 (1), 4R_18_0.7 (2), LED_18_1.C, SHIFT_18.1 (QB)
Q18_2: 4R_18_0.3 (1), 4R_18_0.6 (2), LED_18_2.C, SHIFT_18.2 (QC)
Q18_3: 4R_18_0.4 (1), 4R_18_0.5 (2), LED_18_3.C, SHIFT_18.3 (QD)
Q18_4: 4R_18_1.1, 4R_18_1.8 (2), LED_18_4.C, SHIFT_18.4 (QE)
Q18_5: 4R_18_1.2 (1), 4R_18_1.7 (2), LED_18_5.C, SHIFT_18.5 (QF)
Q18_6: 4R_18_1.3 (1), 4R_18_1.6 (2), LED_18_6.C, SHIFT_18.6 (QG)
Q18_7: 4R_18_1.4 (1), 4R_18_1.5 (2), LED_18_7.C, SHIFT_18.7 (QH)
Q19_0: 4R_19_0.1, 4R_19_0.8 (2), LED_19_0.C, SHIFT_19.15 (QA)
Q19_1: 4R_19_0.2 (1), 4R_19_0.7 (2), LED_19_1.C, SHIFT_19.1 (QB)
Q19_2: 4R_19_0.3 (1), 4R_19_0.6 (2), LED_19_2.C, SHIFT_19.2 (QC)
Q19_3: 4R_19_0.4 (1), 4R_19_0.5 (2), LED_19_3.C, SHIFT_19.3 (QD)
Q19_4: 4R_19_1.1, 4R_19_1.8 (2), LED_19_4.C, SHIFT_19.4 (QE)
Q19_5: 4R_19_1.2 (1), 4R_19_1.7 (2), LED_19_5.C, SHIFT_19.5 (QF)
Q19_6: 4R_19_1.3 (1), 4R_19_1.6 (2), LED_19_6.C, SHIFT_19.6 (QG)
Q19_7: 4R_19_1.4 (1), 4R_19_1.5 (2), LED_19_7.C, SHIFT_19.7 (QH)
Q20_0: 4R_20_0.1, 4R_20_0.8 (2), LED_20_0.C, SHIFT_20.15 (QA)
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

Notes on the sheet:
5V (MR)
11 (SH_CP)
12 (ST_CP)
13 (OE)
14 (DS)

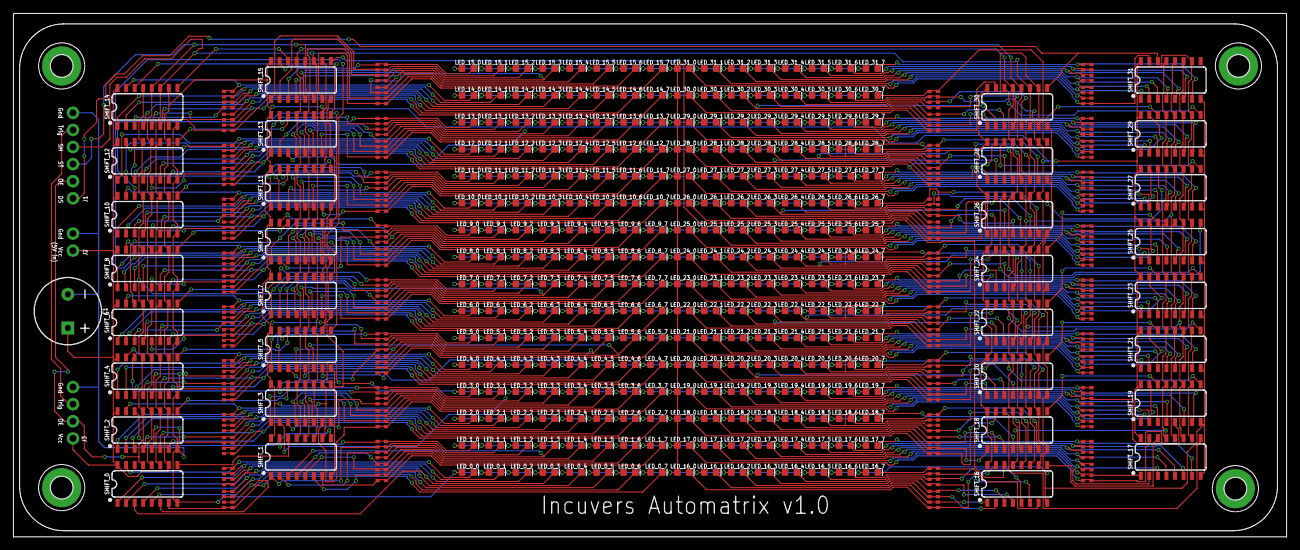
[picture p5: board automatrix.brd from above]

Board: 2 copper layers, 189.1 x 77.7 mm, 360 parts (0 on the bottom side), 293 nets.

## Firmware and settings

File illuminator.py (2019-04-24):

import wiringpi
import time


class Illuminator(object):
    
    def __init__(self):
        wiringpi.wiringPiSetupGpio()

        # setup SPI
        self.channel = 0  # SPI_CE0  or GPIO 08 or Pin25
        self.speed = 500000 
        wiringpi.wiringPiSPISetup(self.channel, self.speed)
        # setup PWM 
        self.PWM_GPIO = 18 # the hardware PWM is GPIO_18 or pin 12
        wiringpi.pinMode(self.PWM_GPIO, 2) # the hardware PWM is on GPIO 18 
        self.brightness = 0
        self.set_brightness(self.brightness)

    def set_brightness(self, val):
        """ Set the global LED brightness (both for the matrix illuminator and the fluorescence)
        Args: val: integer 0-100% brightness
        
        """
        print(val)
        assert val<100, "Brightness value must be a value between 0-100"
        assert val>=0, "Brightness value must be a value between 0-100"
        MAX_DUTY_CYCLE = 1024
        duty_cycle = (100-val)*MAX_DUTY_CYCLE/100
        wiringpi.pwmWrite(self.PWM_GPIO, duty_cycle)

    def brightness_sweep(self):
        """ mainly for show
        """
        for i in range(0,100,1):
            self.set_brightness(i)
            time.sleep(0.005)

    def iterate_matrix(self, start=0, end=4):
        """ iterate LEDs on the matrix
        This is a debugging tool and will be removed
        """
        # turn off matrix while the pattern is set
        self.set_brightness(0)

        for num in range(start, end):
            send_byte = chr(2**num)
            wiringpi.wiringPiSPIDataRW(self.channel, send_byte)
            self.brightness_sweep()
            num += 1
        return
    def flash_pattern(self):
        pass
    def flash_phase_contrast(self):
        pass
    def flash_fluorescence(self):
        pass

if __name__=="__main__":
    illum = Illuminator()
    illum.iterate_matrix(end=8)

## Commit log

2019-04-05 bank schematic
2019-04-08 python model to turn on LEDs
2019-04-24 LED location design
2019-05-06 Version 1.0 of the board
    [automatrix.brd, automatrix.sch]

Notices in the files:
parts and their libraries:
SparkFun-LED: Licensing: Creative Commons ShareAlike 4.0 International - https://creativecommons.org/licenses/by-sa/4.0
